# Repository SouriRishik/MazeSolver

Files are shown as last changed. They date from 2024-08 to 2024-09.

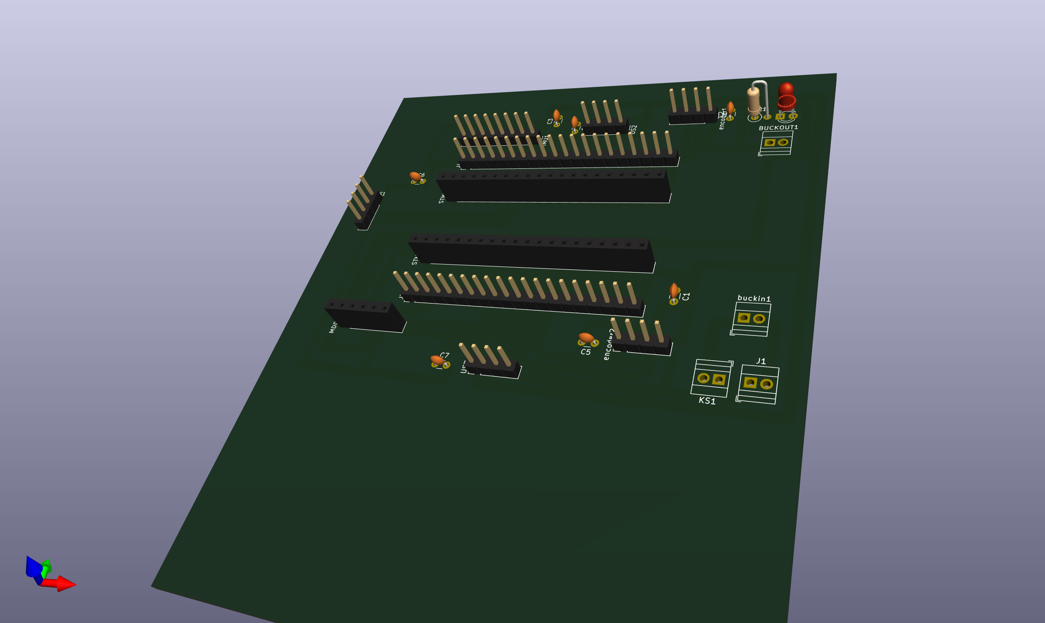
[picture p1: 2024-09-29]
PCB/Maze Solver PCB/FirstSchematic.png

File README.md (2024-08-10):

# MazeSolver
A maze solving bot using algorithm - floodfill
The simulator used to test the robot is mackorone-mms https://github.com/mackorone/mms
Purpose of bot : Technoxian 2024
Dimensions : x n x

This bot was my first project as a part of RoboManipal. I was assigned to work on the Algorithm and its code.

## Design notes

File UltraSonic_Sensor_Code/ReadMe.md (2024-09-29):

Sensor code for all 3 UltraSonic Sensors.

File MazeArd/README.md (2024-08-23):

This is the code at the end of 23rd night (passed into 24th)
Update at this point: Code structure works, Issues with IMU,

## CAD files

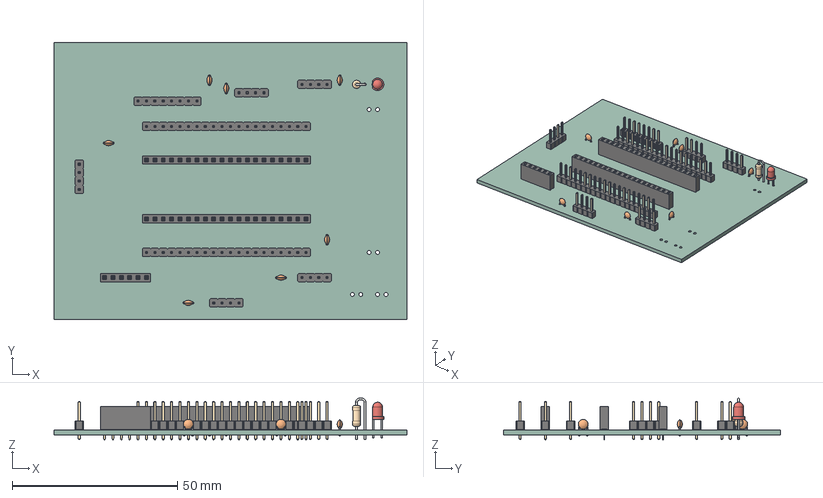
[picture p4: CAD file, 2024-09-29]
PCB/Maze Solver PCB/FirstSchematic.step
106.7 x 83.8 x 12.6 mm
PinHeader_1x04_P254mm_Vertical x 5
PinHeader_1x08_P254mm_Vertical
LED_D3.0mm
PinSocket_1x06_P254mm_Vertical
C_Disc_D30mm_W16mm_P250mm x 7
PinHeader_1x20_P254mm_Vertical x 2
PinSocket_1x20_P254mm_Vertical x 2
R_Axial_DIN0207_L63mm_D25mm_P254mm_Vertical
_autosave-FirstSchematic_PCB

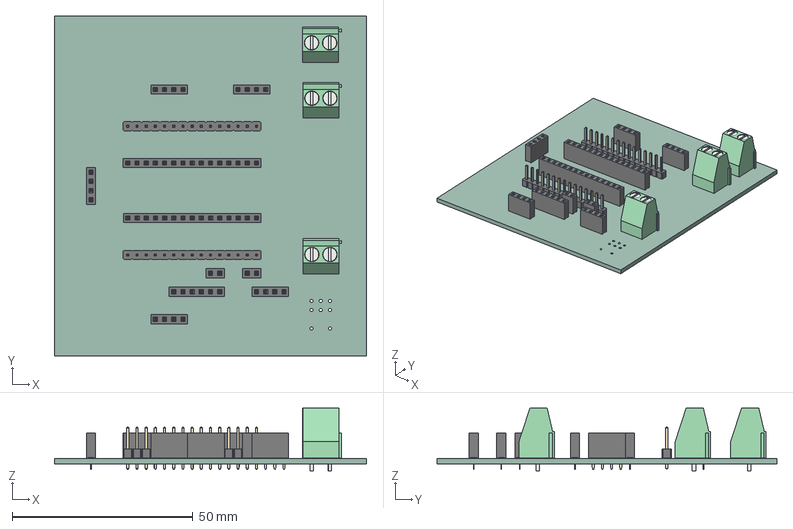
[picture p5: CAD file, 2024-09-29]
PCB/Maze_Solver_Arduino/Maze_Solver_Arduino.step
86.4 x 94.0 x 17.3 mm
PinSocket_1x04_P254mm_Vertical x 5
PinSocket_1x02_P254mm_Vertical x 2
PinSocket_1x15_P254mm_Vertical x 2
TerminalBlock_Phoenix_MKDS_15_2_1x02_P500mm_Horizontal x 3
PinSocket_1x06_P254mm_Vertical
PinHeader_1x15_P254mm_Vertical x 2
Maze_Solver_Arduino_PCB

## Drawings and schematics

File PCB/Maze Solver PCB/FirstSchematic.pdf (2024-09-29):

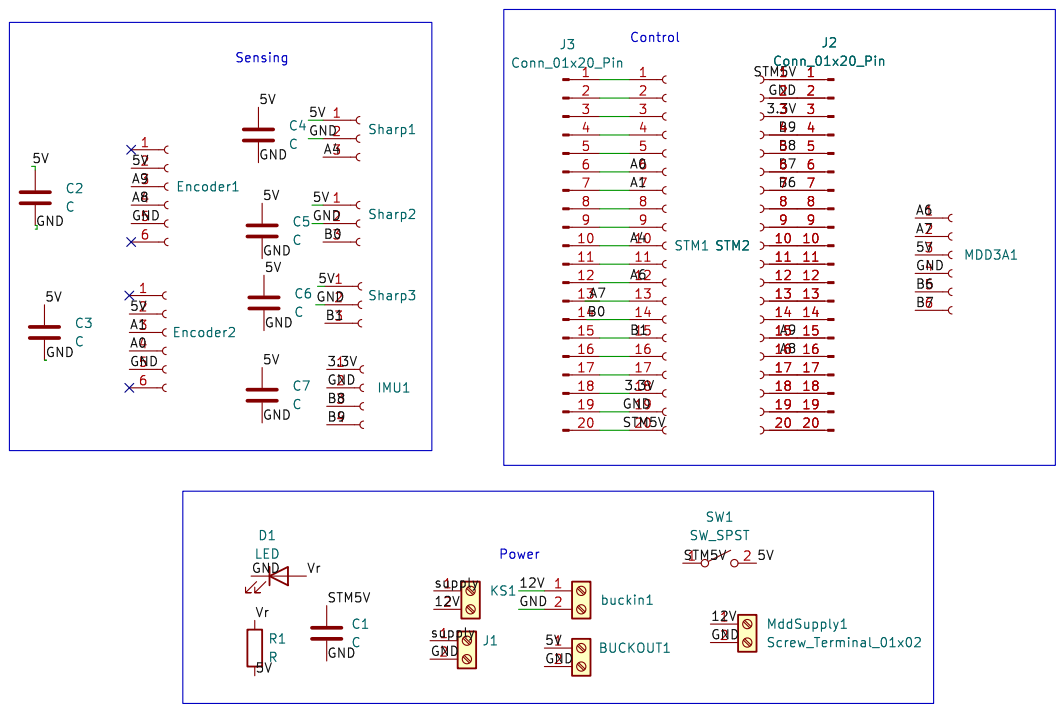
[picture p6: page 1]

Id: 1/1 Title: File: FirstSchematic.kicad_sch Sheet: /

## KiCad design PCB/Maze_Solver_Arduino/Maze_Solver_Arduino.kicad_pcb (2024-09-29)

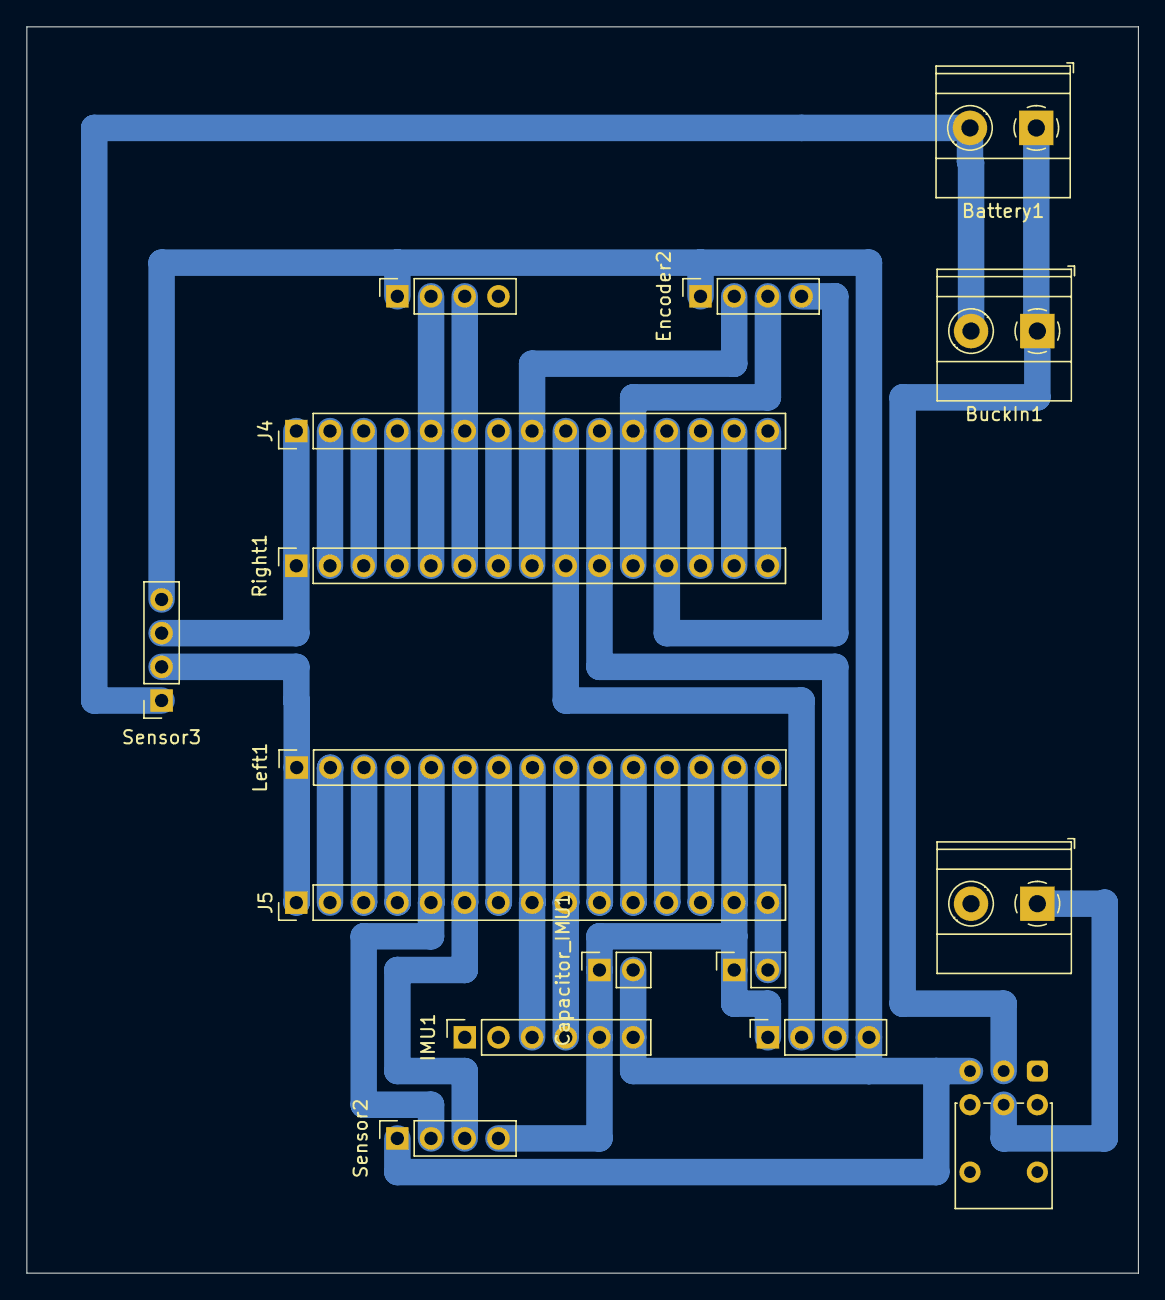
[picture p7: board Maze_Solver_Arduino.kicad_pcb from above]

Board: 2 copper layers, 83.8 x 94.0 mm, 16 parts (0 on the bottom side), 20 nets.

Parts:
Battery1: Screw_Terminal_01x02; TerminalBlock_Phoenix_MKDS-1,5-2_1x02_P5.00mm_Horizontal
BuckIn1: Screw_Terminal_01x02; TerminalBlock_Phoenix_MKDS-1,5-2_1x02_P5.00mm_Horizontal
BuckOut1: Screw_Terminal_01x02; TerminalBlock_Phoenix_MKDS-1,5-2_1x02_P5.00mm_Horizontal
Capacitor_IMU1: Conn_01x02_Socket; PinSocket_1x02_P2.54mm_Vertical
Capacitor_Nano1: Conn_01x02_Socket; PinSocket_1x02_P2.54mm_Vertical
Encoder1, Encoder2: Conn_01x04_Socket; PinSocket_1x04_P2.54mm_Vertical
IMU1: Conn_01x06_Socket; PinSocket_1x06_P2.54mm_Vertical
J4, J5: Conn_01x15_Pin; PinHeader_1x15_P2.54mm_Vertical
KillSwitch1: SW_Push_DPDT; SW_Push_2P2T_Vertical_E-Switch_800UDP8P1A1M6
Left1: Conn_01x15_Socket; PinSocket_1x15_P2.54mm_Vertical
Right1: Conn_01x15_Socket; PinSocket_1x15_P2.54mm_Vertical
Sensor1, Sensor2, Sensor3: Conn_01x04_Socket; PinSocket_1x04_P2.54mm_Vertical

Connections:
5V: BuckOut1.1, Capacitor_Nano1.2, J5.15, KillSwitch1.5 (B), Left1.15
12V: Battery1.1, BuckIn1.1, KillSwitch1.2 (B)
E1: J4.6, Right1.6, Sensor1.3
E2: J5.6, Left1.6, Sensor2.3
E3: J5.1, Left1.1, Sensor3.2
En1A: Encoder1.3, J4.10, Right1.10
En1B: Encoder1.2, J4.9, Right1.9
En2A: Encoder2.2, J4.8, Right1.8
En2B: Encoder2.3, J4.11, Right1.11
GND: Battery1.2, BuckIn1.2, BuckOut1.2, Capacitor_IMU1.1, Capacitor_Nano1.1, Encoder1.1, Encoder2.4, IMU1.5, J4.12, J5.14, Left1.14, Right1.12, Sensor1.4, Sensor2.4, Sensor3.1
M1A: J4.2, Right1.2
M1B: J4.3, Right1.3
M2A: J4.7, Right1.7
M2B: J4.4, Right1.4
SCL: IMU1.4, J5.9, Left1.9
SDA: IMU1.3, J5.8, Left1.8
T1: J4.5, Right1.5, Sensor1.2
T2: J5.5, Left1.5, Sensor2.2
T3: J4.1, Right1.1, Sensor3.3
Vcc: Capacitor_IMU1.2, Encoder1.4, Encoder2.1, IMU1.6, KillSwitch1.3 (C), Sensor1.1, Sensor2.1, Sensor3.4

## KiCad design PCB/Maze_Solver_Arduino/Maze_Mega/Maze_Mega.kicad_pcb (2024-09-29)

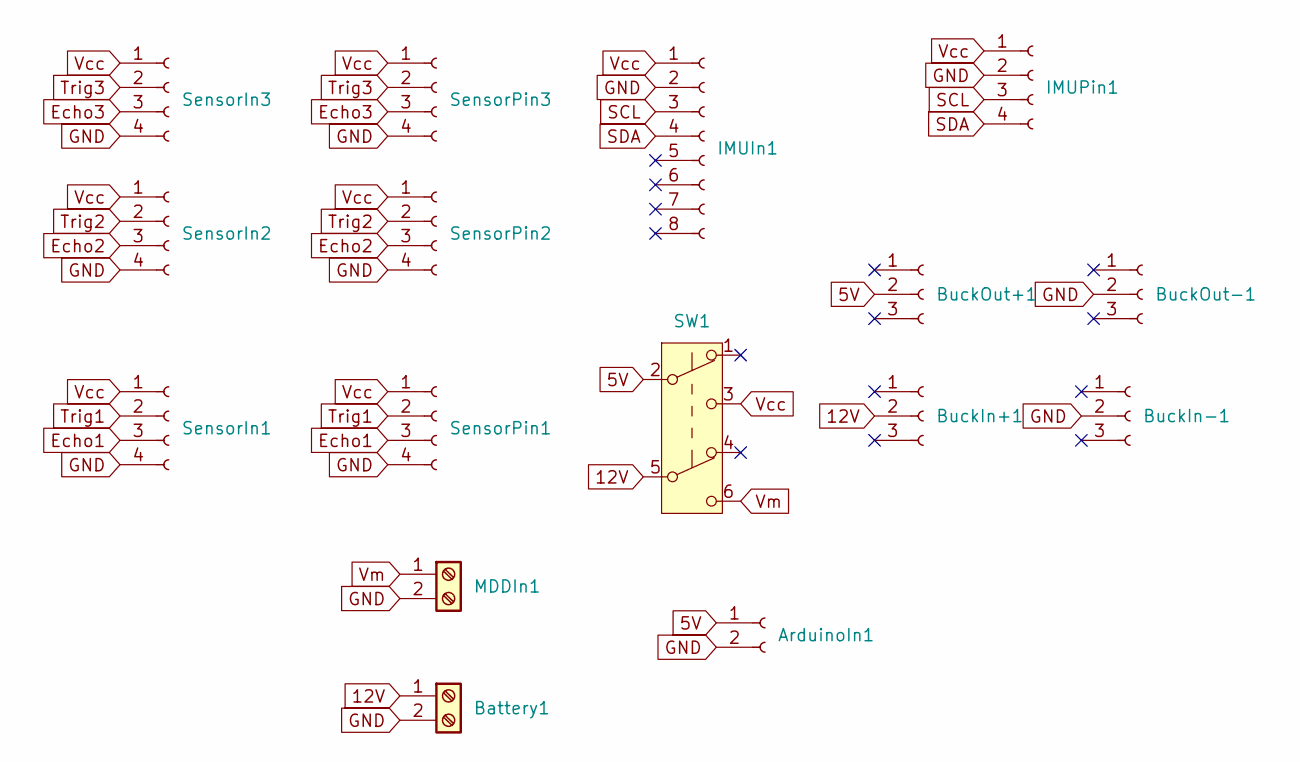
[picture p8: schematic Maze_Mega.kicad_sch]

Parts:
ArduinoIn1: Conn_01x02_Socket; PinSocket_1x02_P2.54mm_Vertical
Battery1: Screw_Terminal_01x02; TerminalBlock_Xinya_XY308-2.54-2P_1x02_P2.54mm_Horizontal
BuckIn+1: Conn_01x03_Socket; PinSocket_1x03_P2.54mm_Vertical
BuckIn-1: Conn_01x03_Socket; PinSocket_1x03_P2.54mm_Vertical
BuckOut+1: Conn_01x03_Socket; PinSocket_1x03_P2.54mm_Vertical
BuckOut-1: Conn_01x03_Socket; PinSocket_1x03_P2.54mm_Vertical
IMUIn1: Conn_01x08_Socket; PinSocket_1x08_P2.54mm_Vertical
IMUPin1: Conn_01x04_Socket; PinSocket_1x04_P2.54mm_Vertical
MDDIn1: Screw_Terminal_01x02; TerminalBlock_Xinya_XY308-2.54-2P_1x02_P2.54mm_Horizontal
SW1: SW_Push_DPDT; SW_Push_2P2T_Vertical_E-Switch_800UDP8P1A1M6
SensorIn1, SensorIn2, SensorIn3: Conn_01x04_Socket; PinSocket_1x04_P2.54mm_Vertical
SensorPin1, SensorPin2, SensorPin3: Conn_01x04_Socket; PinSocket_1x04_P2.54mm_Vertical

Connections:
5V: ArduinoIn1.1, BuckOut+1.2, SW1.2 (B)
12V: Battery1.1, BuckIn+1.2, SW1.5 (B)
Echo1: SensorIn1.3, SensorPin1.3
Echo2: SensorIn2.3, SensorPin2.3
Echo3: SensorIn3.3, SensorPin3.3
GND: ArduinoIn1.2, Battery1.2, BuckIn-1.2, BuckOut-1.2, IMUIn1.2, IMUPin1.2, MDDIn1.2, SensorIn1.4, SensorIn2.4, SensorIn3.4, SensorPin1.4, SensorPin2.4, SensorPin3.4
SCL: IMUIn1.3, IMUPin1.3
SDA: IMUIn1.4, IMUPin1.4
Trig1: SensorIn1.2, SensorPin1.2
Trig2: SensorIn2.2, SensorPin2.2
Trig3: SensorIn3.2, SensorPin3.2
Vcc: IMUIn1.1, IMUPin1.1, SW1.3 (C), SensorIn1.1, SensorIn2.1, SensorIn3.1, SensorPin1.1, SensorPin2.1, SensorPin3.1
Vm: MDDIn1.1, SW1.6 (C)

Board: 2 copper layers, 16 parts (0 on the bottom side), 13 nets, no tracks yet.

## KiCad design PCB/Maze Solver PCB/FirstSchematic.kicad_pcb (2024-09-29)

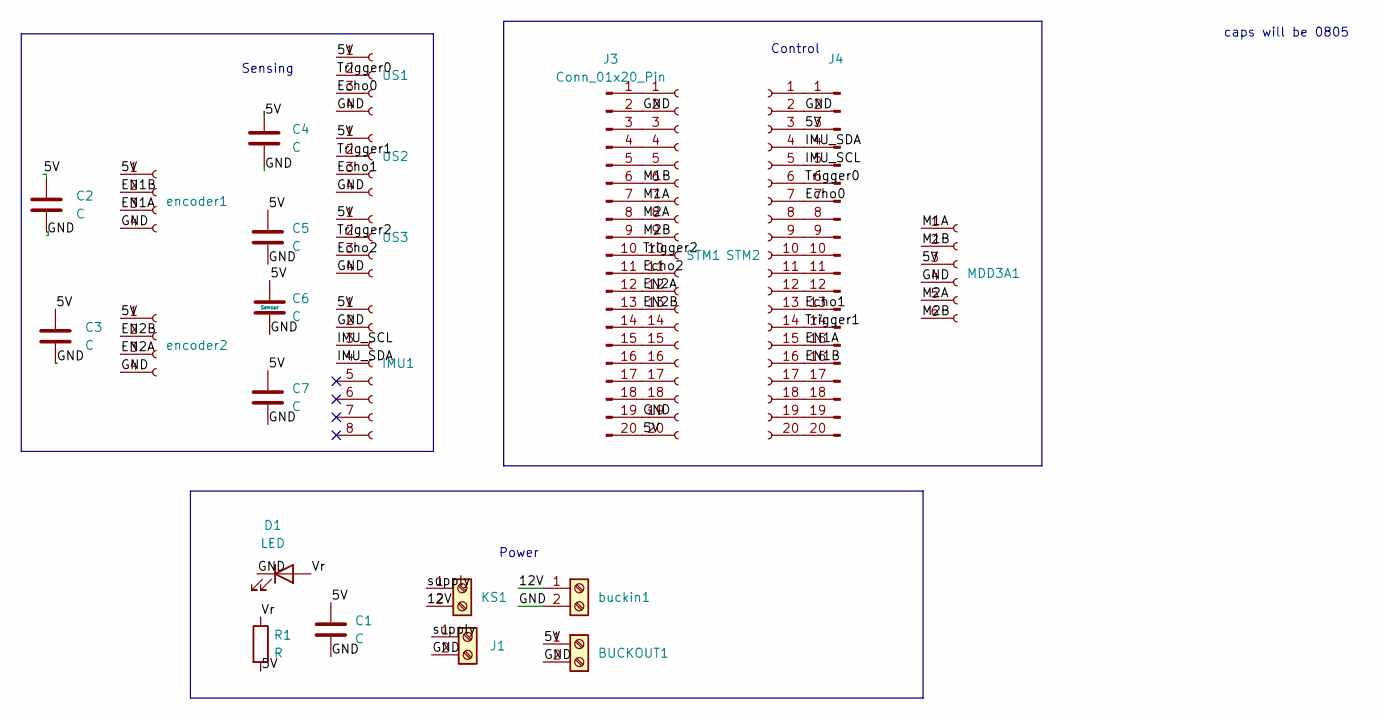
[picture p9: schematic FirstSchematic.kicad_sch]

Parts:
BUCKOUT1: Screw_Terminal_01x02; TerminalBlock_Xinya_XY308-2.54-2P_1x02_P2.54mm_Horizontal
C1, C2, C3, C4, C5, C6, C7: C; C_Disc_D3.0mm_W1.6mm_P2.50mm
D1: LED; LED_D3.0mm
IMU1: Conn_01x08_Socket; PinHeader_1x08_P2.54mm_Vertical
J1: Screw_Terminal_01x02; TerminalBlock_Xinya_XY308-2.54-2P_1x02_P2.54mm_Horizontal
J3, J4: Conn_01x20_Pin; PinHeader_1x20_P2.54mm_Vertical
KS1: Screw_Terminal_01x02; TerminalBlock_Xinya_XY308-2.54-2P_1x02_P2.54mm_Horizontal
MDD3A1: Conn_01x06_Socket; PinSocket_1x06_P2.54mm_Vertical
R1: R; R_Axial_DIN0207_L6.3mm_D2.5mm_P2.54mm_Vertical
STM1, STM2: Conn_01x20_Socket; PinSocket_1x20_P2.54mm_Vertical
US1, US2, US3: Conn_01x04_Socket; PinHeader_1x04_P2.54mm_Vertical
buckin1: Screw_Terminal_01x02; TerminalBlock_Xinya_XY308-2.54-2P_1x02_P2.54mm_Horizontal
encoder1, encoder2: Conn_01x04_Socket; PinHeader_1x04_P2.54mm_Vertical

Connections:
/5V: BUCKOUT1.1, C1.1, C2.1, C3.1, C4.1, C5.1, C6.1, C7.1, IMU1.1, J3.20, J4.3, MDD3A1.3, R1.2, STM1.20, STM2.3, US1.1, US2.1, US3.1, encoder1.1, encoder2.1
/12V: KS1.2, buckin1.1
/EN1A: J4.15, STM2.15, encoder1.3
/EN1B: J4.16, STM2.16, encoder1.2
/EN2A: J3.12, STM1.12, encoder2.3
/EN2B: J3.13, STM1.13, encoder2.2
/Echo0: J4.7, STM2.7, US1.3
/Echo1: J4.13, STM2.13, US2.3
/Echo2: J3.11, STM1.11, US3.3
/GND: BUCKOUT1.2, C1.2, C2.2, C3.2, C4.2, C5.2, C6.2, C7.2, D1.1 (K), IMU1.2, J1.2, J3.2, J3.19, J4.2, MDD3A1.4, STM1.2, STM1.19, STM2.2, US1.4, US2.4, US3.4, buckin1.2, encoder1.4, encoder2.4
/IMU_SCL: IMU1.3, J4.5, STM2.5
/IMU_SDA: IMU1.4, J4.4, STM2.4
/M1A: J3.7, MDD3A1.1, STM1.7
/M1B: J3.6, MDD3A1.2, STM1.6
/M2A: J3.8, MDD3A1.5, STM1.8
/M2B: J3.9, MDD3A1.6, STM1.9
/Trigger0: J4.6, STM2.6, US1.2
/Trigger1: J4.14, STM2.14, US2.2
/Trigger2: J3.10, STM1.10, US3.2
/Vr: D1.2 (A), R1.1
/supply: J1.1, KS1.1
unnamed: J3.1, STM1.1
unnamed: J3.3, STM1.3
unnamed: J3.4, STM1.4
unnamed: J3.5, STM1.5
unnamed: J3.14, STM1.14
unnamed: J3.15, STM1.15
unnamed: J3.16, STM1.16
unnamed: J3.17, STM1.17
unnamed: J3.18, STM1.18
unnamed: J4.1, STM2.1
unnamed: J4.8, STM2.8
unnamed: J4.9, STM2.9
unnamed: J4.10, STM2.10
unnamed: J4.11, STM2.11
unnamed: J4.12, STM2.12
unnamed: J4.17, STM2.17
unnamed: J4.18, STM2.18
unnamed: J4.19, STM2.19
unnamed: J4.20, STM2.20

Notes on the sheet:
Power
caps will be 0805
Control
Sensing

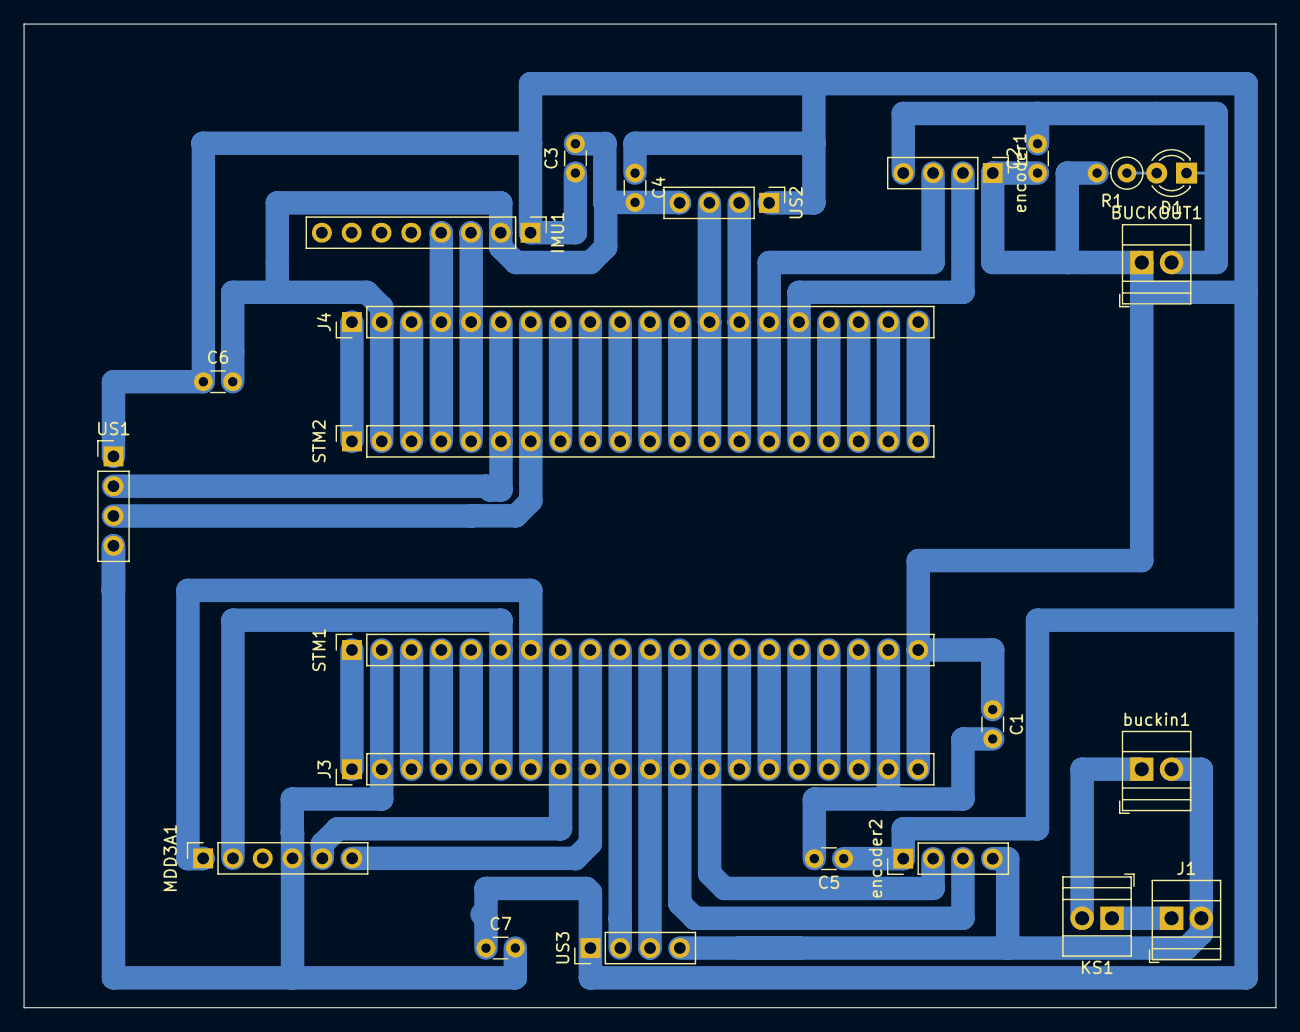
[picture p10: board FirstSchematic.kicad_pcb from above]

Board: 2 copper layers, 106.7 x 83.8 mm, 24 parts (0 on the bottom side), 40 nets.

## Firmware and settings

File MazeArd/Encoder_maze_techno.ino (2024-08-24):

int val;
int encoder0PinA = 3;
int encoder0PinB = 2;
int encoder0Pos = 0;
int encoder0PinALast = LOW;
int n = LOW;

int encoder1PinA = 3;
int encoder1PinB = 2;
int encoder1Pos = 0;
int encoder1PinALast = LOW;
int n1 = LOW;

int trigPin1=4;
int echoPin1=5;

int trigPin2=6;
int echoPin2=7;

int trigPin3=8;
int echoPin3=9;
const byte switchPin = 2;

#include "I2Cdev.h"

#include "MPU6050_6Axis_MotionApps20.h"
//#include "MPU6050.h" // not necessary if using MotionApps include file

// Arduino Wire library is required if I2Cdev I2CDEV_ARDUINO_WIRE implementation
// is used in I2Cdev.h
#if I2CDEV_IMPLEMENTATION == I2CDEV_ARDUINO_WIRE
    #include "Wire.h"
#endif

// class default I2C address is 0x68
// specific I2C addresses may be passed as a parameter here
// AD0 low = 0x68 (default for SparkFun breakout and InvenSense evaluation board)
// AD0 high = 0x69
MPU6050 mpu;
//MPU6050 mpu(0x69); // <-- use for AD0 high

/* =========================================================================
   NOTE: In addition to connection 3.3v, GND, SDA, and SCL, this sketch
   depends on the MPU-6050's INT pin being connected to the Arduino's
   external interrupt #0 pin. On the Arduino Uno and Mega 2560, this is
   digital I/O pin 2.
 * ========================================================================= */

/* =========================================================================
   NOTE: Arduino v1.0.1 with the Leonardo board generates a compile error
   when using Serial.write(buf, len). The Teapot output uses this method.
   The solution requires a modification to the Arduino USBAPI.h file, which
   is fortunately simple, but annoying. This will be fixed in the next IDE
   release. For more info, see these links:

   http://arduino.cc/forum/index.php/topic,109987.0.html
   http://code.google.com/p/arduino/issues/detail?id=958
 * ========================================================================= */



// uncomment "OUTPUT_READABLE_QUATERNION" if you want to see the actual
// quaternion components in a [w, x, y, z] format (not best for parsing
// on a remote host such as Processing or something though)
//#define OUTPUT_READABLE_QUATERNION

// uncomment "OUTPUT_READABLE_EULER" if you want to see Euler angles
// (in degrees) calculated from the quaternions coming from the FIFO.
// Note that Euler angles suffer from gimbal lock (for more info, see
// http://en.wikipedia.org/wiki/Gimbal_lock)
//#define OUTPUT_READABLE_EULER

// uncomment "OUTPUT_READABLE_YAWPITCHROLL" if you want to see the yaw/
// pitch/roll angles (in degrees) calculated from the quaternions coming
// from the FIFO. Note this also requires gravity vector calculations.
// Also note that yaw/pitch/roll angles suffer from gimbal lock (for
// more info, see: http://en.wikipedia.org/wiki/Gimbal_lock)
#define OUTPUT_READABLE_YAWPITCHROLL

// uncomment "OUTPUT_READABLE_REALACCEL" if you want to see acceleration
// components with gravity removed. This acceleration reference frame is
// not compensated for orientation, so +X is always +X according to the
// sensor, just without the effects of gravity. If you want acceleration
// compensated for orientation, us OUTPUT_READABLE_WORLDACCEL instead.
//#define OUTPUT_READABLE_REALACCEL

// uncomment "OUTPUT_READABLE_WORLDACCEL" if you want to see acceleration
// components with gravity removed and adjusted for the world frame of
// reference (yaw is relative to initial orientation, since no magnetometer
// is present in this case). Could be quite handy in some cases.
//#define OUTPUT_READABLE_WORLDACCEL

// uncomment "OUTPUT_TEAPOT" if you want output that matches the
// format used for the InvenSense teapot demo
//#define OUTPUT_TEAPOT



#define INTERRUPT_PIN 2 
#define INTERRUPT_PIN1 3 // use pin 2 on Arduino Uno & most boards
#define LED_PIN 13 // (Arduino is 13, Teensy is 11, Teensy++ is 6)
bool blinkState = false;

// MPU control/status vars
bool dmpReady = false;  // set true if DMP init was successful
uint8_t mpuIntStatus;   // holds actual interrupt status byte from MPU
uint8_t devStatus;      // return status after each device operation (0 = success, !0 = error)
uint16_t packetSize;    // expected DMP packet size (default is 42 bytes)
uint16_t fifoCount;     // count of all bytes currently in FIFO
uint8_t fifoBuffer[64]; // FIFO storage buffer

// orientation/motion vars
Quaternion q;           // [w, x, y, z]         quaternion container
VectorInt16 aa;         // [x, y, z]            accel sensor measurements
VectorInt16 aaReal;     // [x, y, z]            gravity-free accel sensor measurements
VectorInt16 aaWorld;    // [x, y, z]            world-frame accel sensor measurements
VectorFloat gravity;    // [x, y, z]            gravity vector
float euler[3];         // [psi, theta, phi]    Euler angle container
float ypr[3];           // [yaw, pitch, roll]   yaw/pitch/roll container and gravity vector

// packet structure for InvenSense teapot demo
uint8_t teapotPacket[14] = { '$', 0x02, 0,0, 0,0, 0,0, 0,0, 0x00, 0x00, '\r', '\n' };



// ================================================================
// ===               INTERRUPT DETECTION ROUTINE                ===
// ================================================================

volatile bool mpuInterrupt = false;     // indicates whether MPU interrupt pin has gone high
void dmpDataReady() {
    mpuInterrupt = true;
}

void setup() {
  //ENCODER PINS
  pinMode (encoder0PinA, INPUT_PULLUP);
  pinMode (encoder0PinB, INPUT_PULLUP);
    pinMode (encoder1PinA, INPUT_PULLUP);
  pinMode (encoder1PinB, INPUT_PULLUP);
  //ULTRA SONIC PINS
  pinMode(trigPin1, OUTPUT);
  pinMode(echoPin1, INPUT);
  pinMode(trigPin2, OUTPUT);
  pinMode(echoPin2, INPUT);
  pinMode(trigPin3, OUTPUT);
  pinMode(echoPin3, INPUT);
  pinMode(switchPin, INPUT_PULLUP);
  attachInterrupt(digitalPinToInterrupt(encoder0PinA), handleSwitch, CHANGE);
  attachInterrupt(digitalPinToInterrupt(encoder1PinA), handleSwitch1, CHANGE);
      #if I2CDEV_IMPLEMENTATION == I2CDEV_ARDUINO_WIRE
        Wire.begin();
        Wire.setClock(400000); // 400kHz I2C clock. Comment this line if having compilation difficulties
    #elif I2CDEV_IMPLEMENTATION == I2CDEV_BUILTIN_FASTWIRE
        Fastwire::setup(400, true);
    #endif

    // initialize serial communication
    // (115200 chosen because it is required for Teapot Demo output, but it's
    // really up to you depending on your project)
    Serial.begin(115200);
    while (!Serial); // wait for Leonardo enumeration, others continue immediately

    // NOTE: 8MHz or slower host processors, like the Teensy @ 3.3V or Arduino
    // Pro Mini running at 3.3V, cannot handle this baud rate reliably due to
    // the baud timing being too misaligned with processor ticks. You must use
    // 38400 or slower in these cases, or use some kind of external separate
    // crystal solution for the UART timer.

    // initialize device
    Serial.println(F("Initializing I2C devices..."));
    mpu.initialize();
    pinMode(INTERRUPT_PIN, INPUT);

    // verify connection
    Serial.println(F("Testing device connections..."));
    Serial.println(mpu.testConnection() ? F("MPU6050 connection successful") : F("MPU6050 connection failed"));

    // wait for ready
    //Serial.println(F("\nSend any character to begin DMP programming and demo: "));
    //while (Serial.available() && Serial.read()); // empty buffer
    //while (!Serial.available());                 // wait for data
    //while (Serial.available() && Serial.read()); // empty buffer again

    // load and configure the DMP
    Serial.println(F("Initializing DMP..."));
    devStatus = mpu.dmpInitialize();

    // supply your own gyro offsets here, scaled for min sensitivity
    mpu.setXGyroOffset(220);
    mpu.setYGyroOffset(76);
    mpu.setZGyroOffset(-85);
    mpu.setZAccelOffset(1788); // 1688 factory default for my test chip

    // make sure it worked (returns 0 if so)
    if (devStatus == 0) {
        // Calibration Time: generate offsets and calibrate our MPU6050
        mpu.CalibrateAccel(6);
        mpu.CalibrateGyro(6);
        mpu.PrintActiveOffsets();
        // turn on the DMP, now that it's ready
        Serial.println(F("Enabling DMP..."));
        mpu.setDMPEnabled(true);

        // enable Arduino interrupt detection
        Serial.print(F("Enabling interrupt detection (Arduino external interrupt "));
        Serial.print(digitalPinToInterrupt(INTERRUPT_PIN));
        Serial.println(F(")..."));
        attachInterrupt(digitalPinToInterrupt(INTERRUPT_PIN), dmpDataReady, RISING);
        mpuIntStatus = mpu.getIntStatus();

        // set our DMP Ready flag so the main loop() function knows it's okay to use it
        Serial.println(F("DMP ready! Waiting for first interrupt..."));
        dmpReady = true;

        // get expected DMP packet size for later comparison
        packetSize = mpu.dmpGetFIFOPacketSize();
    } else {
        // ERROR!
        // 1 = initial memory load failed
        // 2 = DMP configuration updates failed
        // (if it's going to break, usually the code will be 1)
        Serial.print(F("DMP Initialization failed (code "));
        Serial.print(devStatus);
        Serial.println(F(")"));
    }

    // configure LED for output
    pinMode(LED_PIN, OUTPUT);
}

void loop() {
  //Reading encoder value

  //Ultrasonic code
  UltraSonic();
     // if programming failed, don't try to do anything
    if (!dmpReady) return;
    // read a packet from FIFO
    if (mpu.dmpGetCurrentFIFOPacket(fifoBuffer)) { // Get the Latest packet 
        #ifdef OUTPUT_READABLE_QUATERNION
            // display quaternion values in easy matrix form: w x y z
            mpu.dmpGetQuaternion(&q, fifoBuffer);
            Serial.print("quat\t");
            Serial.print(q.w);
            Serial.print("\t");
            Serial.print(q.x);
            Serial.print("\t");
            Serial.print(q.y);
            Serial.print("\t");
            Serial.println(q.z);
        #endif

        #ifdef OUTPUT_READABLE_EULER
            // display Euler angles in degrees
            mpu.dmpGetQuaternion(&q, fifoBuffer);
            mpu.dmpGetEuler(euler, &q);
            Serial.print("euler\t");
            Serial.print(euler[0] * 180/M_PI);
            Serial.print("\t");
            Serial.print(euler[1] * 180/M_PI);
            Serial.print("\t");
            Serial.println(euler[2] * 180/M_PI);
        #endif

        #ifdef OUTPUT_READABLE_YAWPITCHROLL
            // display Euler angles in degrees
            mpu.dmpGetQuaternion(&q, fifoBuffer);
            mpu.dmpGetGravity(&gravity, &q);
            mpu.dmpGetYawPitchRoll(ypr, &q, &gravity);
            Serial.print("ypr\t");
            Serial.print(ypr[0] * 180/M_PI);
            Serial.print("\t");
            Serial.print(ypr[1] * 180/M_PI);
            Serial.print("\t");
            Serial.println(ypr[2] * 180/M_PI);
        #endif

        #ifdef OUTPUT_READABLE_REALACCEL
            // display real acceleration, adjusted to remove gravity
            mpu.dmpGetQuaternion(&q, fifoBuffer);
            mpu.dmpGetAccel(&aa, fifoBuffer);
            mpu.dmpGetGravity(&gravity, &q);
            mpu.dmpGetLinearAccel(&aaReal, &aa, &gravity);
            Serial.print("areal\t");
            Serial.print(aaReal.x);
            Serial.print("\t");
            Serial.print(aaReal.y);
            Serial.print("\t");
            Serial.println(aaReal.z);
        #endif

        #ifdef OUTPUT_READABLE_WORLDACCEL
            // display initial world-frame acceleration, adjusted to remove gravity
            // and rotated based on known orientation from quaternion
            mpu.dmpGetQuaternion(&q, fifoBuffer);
            mpu.dmpGetAccel(&aa, fifoBuffer);
            mpu.dmpGetGravity(&gravity, &q);
            mpu.dmpGetLinearAccel(&aaReal, &aa, &gravity);
            mpu.dmpGetLinearAccelInWorld(&aaWorld, &aaReal, &q);
            Serial.print("aworld\t");
            Serial.print(aaWorld.x);
            Serial.print("\t");
            Serial.print(aaWorld.y);
            Serial.print("\t");
            Serial.println(aaWorld.z);
        #endif
    
        #ifdef OUTPUT_TEAPOT
            // display quaternion values in InvenSense Teapot demo format:
            teapotPacket[2] = fifoBuffer[0];
            teapotPacket[3] = fifoBuffer[1];
            teapotPacket[4] = fifoBuffer[4];
            teapotPacket[5] = fifoBuffer[5];
            teapotPacket[6] = fifoBuffer[8];
            teapotPacket[7] = fifoBuffer[9];
            teapotPacket[8] = fifoBuffer[12];
            teapotPacket[9] = fifoBuffer[13];
            Serial.write(teapotPacket, 14);
            teapotPacket[11]++; // packetCount, loops at 0xFF on purpose
        #endif

        // blink LED to indicate activity
        blinkState = !blinkState;
        digitalWrite(LED_PIN, blinkState);
    }

}

int UltraSonic(){
  long duration1, distance1;
  digitalWrite(trigPin1, LOW);  // Added this line
  delayMicroseconds(2); // Added this line
  digitalWrite(trigPin1, HIGH);
  delayMicroseconds(10); // Added this line
  digitalWrite(trigPin1, LOW);
  duration1 = pulseIn(echoPin1, HIGH);
  distance1 = (duration1/2) / 29.1;

   if (distance1 >= 500 || distance1 <= 0){
    Serial.println("Out of range");
  }
  else {
    Serial.print ( "Sensor1  ");
    Serial.print ( distance1);
    Serial.println("cm");
  }

long duration2, distance2;
  digitalWrite(trigPin2, LOW);  // Added this line
  delayMicroseconds(2); // Added this line
  digitalWrite(trigPin2, HIGH);
  delayMicroseconds(10); // Added this line
  digitalWrite(trigPin2, LOW);
  duration2 = pulseIn(echoPin2, HIGH);
  distance2= (duration2/2) / 29.1;

   if (distance2 >= 500 || distance2 <= 0){
    Serial.println("Out of range");
  }
  else {
    Serial.print("Sensor2  ");
    Serial.print(distance2);
    Serial.println("cm");
  }
  long duration3, distance3;
  digitalWrite(trigPin3, LOW);  // Added this line
  delayMicroseconds(2); // Added this line
  digitalWrite(trigPin3, HIGH);
  delayMicroseconds(10); // Added this line
  digitalWrite(trigPin3, LOW);
  duration3 = pulseIn(echoPin3, HIGH);
  distance3= (duration3/2) / 29.1;

   if (distance3 >= 500 || distance3 <= 0){
    Serial.println("Out of range");
  }
  else {
    Serial.print("Sensor3  ");
    Serial.print(distance3);
    Serial.println("cm");
  }

}

void handleSwitch() {
  n = digitalRead(encoder0PinA);
  if ((encoder0PinALast == LOW) && (n == HIGH)) {
    if (digitalRead(encoder0PinB) == LOW) {
      encoder0Pos--;
      //Serial.println("Entered minus");
    } else {
      encoder0Pos++;
    }
    Serial.println("READINGS");
    Serial.print (encoder0Pos);
    Serial.print ("\n");
  }

  encoder0PinALast=n;
}

void handleSwitch1() {
  n1 = digitalRead(encoder1PinA);
  if ((encoder1PinALast == LOW) && (n1 == HIGH)) {
    if (digitalRead(encoder1PinB) == LOW) {
      encoder1Pos--;
      //Serial.println("Entered minus");
    } else {
      encoder1Pos++;
    }
    Serial.println("READINGS en2");
    Serial.print (encoder1Pos);
    Serial.print ("\n");
  }

  encoder1PinALast=n;
}

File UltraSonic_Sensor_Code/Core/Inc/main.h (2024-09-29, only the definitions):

#define LED_Pin GPIO_PIN_13
#define LED_GPIO_Port GPIOC
#define TRIG1_Pin GPIO_PIN_0
#define TRIG1_GPIO_Port GPIOA
#define TRIG2_Pin GPIO_PIN_1
#define TRIG2_GPIO_Port GPIOA
#define TRIG3_Pin GPIO_PIN_2
#define TRIG3_GPIO_Port GPIOA
#define Echo1_Pin GPIO_PIN_8
#define Echo1_GPIO_Port GPIOA
#define Echo2_Pin GPIO_PIN_9
#define Echo2_GPIO_Port GPIOA
#define Echo3_Pin GPIO_PIN_10
#define Echo3_GPIO_Port GPIOA

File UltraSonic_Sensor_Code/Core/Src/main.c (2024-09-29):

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
/* Includes ------------------------------------------------------------------*/
#include "main.h"
#include "usb_device.h"

/* USER CODE BEGIN Includes */
#include "usbd_cdc_if.h"
#include "hcSR04.h"
#include "stdio.h"

/* USER CODE END Includes */

TIM_HandleTypeDef htim1;
TIM_HandleTypeDef htim2;

void SystemClock_Config(void);
static void MX_GPIO_Init(void);
static void MX_TIM1_Init(void);
static void MX_TIM2_Init(void);
/* USER CODE BEGIN 0 */




// Let's write the callback function





/* USER CODE END 0 */

/**
  * @brief  The application entry point.
  * @retval int
  */
int main(void)
{

  /* MCU Configuration--------------------------------------------------------*/

  /* Reset of all peripherals, Initializes the Flash interface and the Systick. */
  HAL_Init();

  /* Configure the system clock */
  SystemClock_Config();

  /* Initialize all configured peripherals */
  MX_GPIO_Init();
  MX_TIM1_Init();
  MX_USB_DEVICE_Init();
  MX_TIM2_Init();
  /* USER CODE BEGIN 2 */
  HAL_TIM_IC_Start_IT(&htim1 ,TIM_CHANNEL_1);
  HAL_TIM_IC_Start_IT(&htim1 ,TIM_CHANNEL_2);
  HAL_TIM_IC_Start_IT(&htim1 ,TIM_CHANNEL_3);
  HAL_TIM_Base_Start(&htim2);
  /* USER CODE END 2 */

  /* Infinite loop */
  /* USER CODE BEGIN WHILE */
  while (1)
  {
    /* USER CODE END WHILE */

    /* USER CODE BEGIN 3 */
	  HCSR04_Trigger();
	  HAL_Delay(1000);
  }
  /* USER CODE END 3 */
}

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


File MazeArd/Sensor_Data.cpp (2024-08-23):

#include <Wire.h>
#include "I2Cdev.h"
#include "MPU6050_6Axis_MotionApps20.h"
#include "Sensor_Data.h"

RobotControl* RobotControl::instance = nullptr;

// Global variables
int val;
int encoder0PinA = 3;
int encoder0PinB = 4;
int encoder0Pos = 0;
int encoder0PinALast = LOW;
int n = LOW;

int yaw;

int encoder1PinA = 2;
int encoder1PinB = 5;
int encoder1Pos = 0;
int encoder1PinALast = LOW;
int n1 = LOW;

int trigPin1 = A3;
int echoPin1 = A4;

int trigPin2 = A1;
int echoPin2 = A2;

int trigPin3 =A5;
int echoPin3 = A6;
const byte switchPin = 2;

#define INTERRUPT_PIN 2 
#define INTERRUPT_PIN1 3 

#define INTERRUPT_EN 18
bool blinkState = false;

// MPU control/status vars
bool dmpReady = false;  
uint8_t mpuIntStatus;   
uint8_t devStatus;      
uint16_t packetSize;    
uint16_t fifoCount;     
uint8_t fifoBuffer[64]; 

Quaternion q;           
VectorInt16 aa;         
VectorInt16 aaReal;     
VectorInt16 aaWorld;    
VectorFloat gravity;    
float euler[3];         
float ypr[3];           

uint8_t teapotPacket[14] = { '$', 0x02, 0,0, 0,0, 0,0, 0,0, 0x00, 0x00, '\r', '\n' };

volatile bool mpuInterrupt = false;

MPU6050 mpu;

void RobotControl::initialize() {
    // Initialize serial communication
    Serial.begin(9600);
    while (!Serial);

    // Initialize I2C and MPU6050
    #if I2CDEV_IMPLEMENTATION == I2CDEV_ARDUINO_WIRE
        Wire.begin();
        Wire.setClock(500000);
    #elif I2CDEV_IMPLEMENTATION == I2CDEV_BUILTIN_FASTWIRE
        Fastwire::setup(400, true);
    #endif

    // Initialize MPU6050
    mpu.initialize();

    pinMode(INTERRUPT_PIN, INPUT);
    
    // Setup encoder pins
    pinMode(encoder0PinA, INPUT_PULLUP);
    pinMode(encoder0PinB, INPUT_PULLUP);
    pinMode(encoder1PinA, INPUT_PULLUP);
    pinMode(encoder1PinB, INPUT_PULLUP);
    
    // Setup ultrasonic pins
    pinMode(trigPin1, OUTPUT);
    pinMode(echoPin1, INPUT);
    pinMode(trigPin2, OUTPUT);
    pinMode(echoPin2, INPUT);
    pinMode(trigPin3, OUTPUT);
    pinMode(echoPin3, INPUT);
    pinMode(switchPin, INPUT_PULLUP);

    instance = this; // Store the current instance

    attachInterrupt(digitalPinToInterrupt(encoder0PinA), []() { instance->handleSwitch(); }, CHANGE);
    attachInterrupt(digitalPinToInterrupt(encoder1PinA), []() { instance->handleSwitch1(); }, CHANGE);
    attachInterrupt(digitalPinToInterrupt(INTERRUPT_PIN), []() { instance->dmpDataReady(); }, RISING);
    //attachInterrupt(digitalPinToInterrupt(INTERRUPT_PIN), RISING);

    devStatus = mpu.dmpInitialize();
    mpu.setXGyroOffset(220);
    mpu.setYGyroOffset(76);
    mpu.setZGyroOffset(-85);
    mpu.setZAccelOffset(1788);

    if (devStatus == 0) {
      Serial.println("dev Status 0");
        mpu.CalibrateAccel(6);
        mpu.CalibrateGyro(6);
        mpu.PrintActiveOffsets();
        mpu.setDMPEnabled(true);
        mpuIntStatus = mpu.getIntStatus();
        dmpReady = true;
        packetSize = mpu.dmpGetFIFOPacketSize();
    } else {
        Serial.print(F("DMP Initialization failed (code "));
        Serial.print(devStatus);
        Serial.println(F(")"));
    }
}

// void RobotControl::run() {
//     while (true) {
//         UltraSonic();
//         if (!dmpReady) continue;

//         if (mpu.dmpGetCurrentFIFOPacket(fifoBuffer)) {
//             #ifdef OUTPUT_READABLE_YAWPITCHROLL
//                 mpu.dmpGetQuaternion(&q, fifoBuffer);
//                 mpu.dmpGetGravity(&gravity, &q);
//                 mpu.dmpGetYawPitchRoll(ypr, &q, &gravity);
//                 Serial.print("4");
//                 Serial.println(ypr[0] * 180 / M_PI);
//                 yaw = ypr[0] * 180 / M_PI;
//             #endif

//         }
//     }
// } 

float RobotControl::CalculateYaw()
{
  Serial.println("Calculating Yaw...");
    if (dmpReady)
    {
        if (mpu.dmpGetCurrentFIFOPacket(fifoBuffer)) {
            #ifdef OUTPUT_READABLE_YAWPITCHROLL
                mpu.dmpGetQuaternion(&q, fifoBuffer);
                mpu.dmpGetGravity(&gravity, &q);
                mpu.dmpGetYawPitchRoll(ypr, &q, &gravity);
                Serial.println("4 ");
                Serial.println(ypr[0] * 180 / M_PI);
                yaw = ypr[0] * 180 / M_PI;
            #endif

        }
    }
    return yaw;
}

//Different code for IMU
// float RobotControl::CalculateYaw()
// {
// if (!dmpReady) continue;

//         if (mpu.dmpGetCurrentFIFOPacket(fifoBuffer)) {
//             #ifdef OUTPUT_READABLE_YAWPITCHROLL
//                 mpu.dmpGetQuaternion(&q, fifoBuffer);
//                 mpu.dmpGetGravity(&gravity, &q);
//                 mpu.dmpGetYawPitchRoll(ypr, &q, &gravity);
//                 Serial.print("4");
//                 Serial.println(ypr[0] * 180 / M_PI);
//                 yaw = ypr[0] * 180 / M_PI;

//             #endif
//             blinkState = !blinkState;
//             digitalWrite(LED_PIN, blinkState);
//             return yaw;

//         }
//     }
// void RobotControl::getYPR(float yaw) {
//     yaw = ypr[0];
    
// }


void RobotControl::dmpDataReady() {
    mpuInterrupt = true;
}
 
long RobotControl::UltraSonic1() {
    long duration1, distance1;
    digitalWrite(trigPin1, LOW);
    delayMicroseconds(2);
    digitalWrite(trigPin1, HIGH);
    delayMicroseconds(10);
    digitalWrite(trigPin1, LOW);
    duration1 = pulseIn(echoPin1, HIGH);
    distance1 = (duration1 / 2) / 29.1;

    if (distance1 >= 500 || distance1 <= 0) {
        Serial.println("Out of range1");
    } else {
        Serial.print("1 ");
        Serial.println(distance1);
    }
    return distance1;
}

long RobotControl::UltraSonic2()
{
    long duration2, distance2;
    digitalWrite(trigPin2, LOW);
    delayMicroseconds(2);
    digitalWrite(trigPin2, HIGH);
    delayMicroseconds(10);
    digitalWrite(trigPin2, LOW);
    duration2 = pulseIn(echoPin2, HIGH);
    distance2 = (duration2 / 2) / 29.1;

    if (distance2 >= 500 || distance2 <= 0) {
        Serial.println("Out of range");
    } else {
         Serial.print("2 ");
         Serial.println(distance2);
    }
    return distance2;
}

long RobotControl::UltraSonic3()
{
    
    long duration3, distance3;
    digitalWrite(trigPin3, LOW);
    delayMicroseconds(2);
    digitalWrite(trigPin3, HIGH);
    delayMicroseconds(10);
    digitalWrite(trigPin3, LOW);
    duration3 = pulseIn(echoPin3, HIGH);
    distance3 = (duration3 / 2) / 29.1;

    if (distance3 >= 500 || distance3 <= 0) {
        Serial.println("Out of range3");
    } else {
         Serial.print("3 ");
         Serial.println(distance3);
    }
    return distance3;
}

void RobotControl::handleSwitch() {
    n = digitalRead(encoder0PinA);
    if ((encoder0PinALast == LOW) && (n == HIGH)) {
        if (digitalRead(encoder0PinB) == LOW) {
            encoder0Pos--;
        } else {
            encoder0Pos++;
        }
         Serial.print("5 ");
         Serial.println(encoder0Pos);
    }
    encoder0PinALast = n;
}
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

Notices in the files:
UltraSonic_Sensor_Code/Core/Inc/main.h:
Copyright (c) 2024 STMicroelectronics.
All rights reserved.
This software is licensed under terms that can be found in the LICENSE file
